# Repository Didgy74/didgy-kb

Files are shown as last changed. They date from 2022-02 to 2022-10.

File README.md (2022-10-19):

# didgy-kb
A catch-all repo for any keyboards I design.

These designs are all designed with [Ergogen](https://github.com/ergogen/ergogen).

# Mitten

This design has the following properties:
 - 30 keys
 - Split
 - Columnar stagger
 - Column splay on the outer columns
 - Wireless
 - Reversible PCB
 - (Very) Low profile (Choc Mini)
 - Choc spacing in Y direction
 - MX spacing in X direction
 - 1u keys for fingers
 - 1.5u keys for thumbs
 - Includes mountplate
 - Standard ProMicro support (Note that it's wireless only, so use a compatible MCU with Bluetooth connectivity)

In short, this design is heavily inspired by the [Ferris](https://github.com/pierrechevalier83/ferris) (or more specifically, the [Sweep](https://github.com/davidphilipbarr/Sweep)). This keyboard is very similar with a few key design differences:
 - Stagger adjusted for hands that have a short index finger
 - Outer columns are splayed
 - Removed one key from innermost column and outermost column.
 - Choc Mini support
 - Larger thumbkeys (1.5u)
 - Designed for wireless operation **only**
 - Includes mountplate

### Information

**Main PCB thickness:** 1.6mm

**Mount plate thickness:** 1.6mm

Mount plate is mostly for making the design sturdier and holding keys in place a bit better.

**Connector:** Molex PicoBlade 2-pin horizontal (Often mislabeled as Micro JST in stores)

**Key switches:** Kailh Choc Mini PG1232 (https://www.aliexpress.com/item/4000277394324.html)

Personal note: Try using 35g springs with linear (black) motion.

**MCU sockets:** Mill-Max Interconnect Machined Pin Socket. Pitch 2.54mm. Height above PCB: 7mm.
Part no. 801-XX-XXX-10-001000. You need at least 12 pins wide, any more can be broken off.

**Underside material:** Neoprene (need actual testing still)

**Keycaps:** MBK profile Choc (https://splitkb.com/collections/switches-and-keycaps/products/blank-mbk-choc-low-profile-keycaps)

**Power switch:** 7-pin micro SPDT

**MCU:** nice!nano

Xiao Seeed was considered for its smaller size, but since battery is mounted under the MCU, the battery would have to become too small anyways.

**MCU socket pins:** Mill-Max gold pins. Part no. 3320-0-00-15-00-00-03-0. (https://splitkb.com/collections/keyboard-parts/products/mill-max-low-profile-sockets?variant=32170972020813)

These could be thicker / longer, fit is not very good.

### Instructions

The MCU has to be mounted **face down** by default.

By default, all jumpers need to be shorted on the **opposite side** of where components are mounted.

### Future design work
I intend to keep iterating on this design over time, here are a few ideas I would like to eventually realize:
 - Add wired connectivity (but only if I, or a number of users request it)
 - Remove a key from the pinky column
 - **Possiby** try out a very low profile rotary encoder
 - Tighter vertical keyspacing (would require custom keycap work)
 - Choc Mini support
 - Add instructions for automatically routing the PCB

Other than that, I'll probably make adjustments to the stagger and key placement over time.

### Configuration 

While this is currently configured to fit my hands specifically, I am very much interested in creating a very parametric design. I try to keep the .yaml file commented enough to easily understand how to modify it. For instance, you could easily switch to using MX spacing by modifying the lines
```yaml
  keyspacingx: cx
  keyspacingy: cy
```
to
```yaml
  keyspacingx: u
  keyspacingy: u
```
and even switch to MX switch footprints by finding the YAML variable named `key_footprints`. Other configurable values currently include margin around key switches, rotation of the home thumbkey. I plan to add more of configuration in the future.

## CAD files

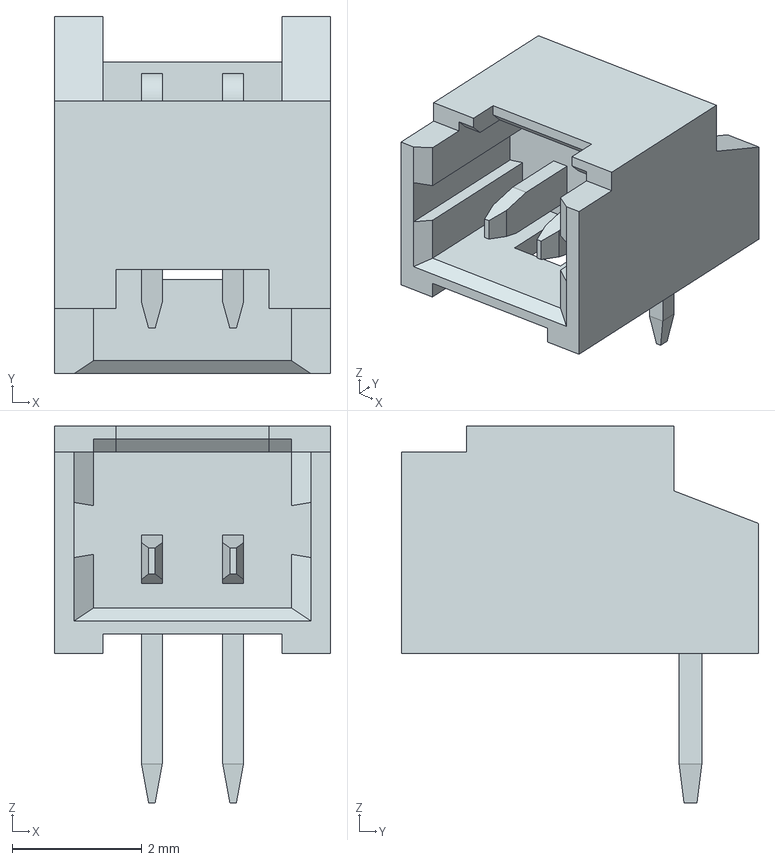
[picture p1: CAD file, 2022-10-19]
530480260.stp
4.25 x 5.50 x 5.80 mm

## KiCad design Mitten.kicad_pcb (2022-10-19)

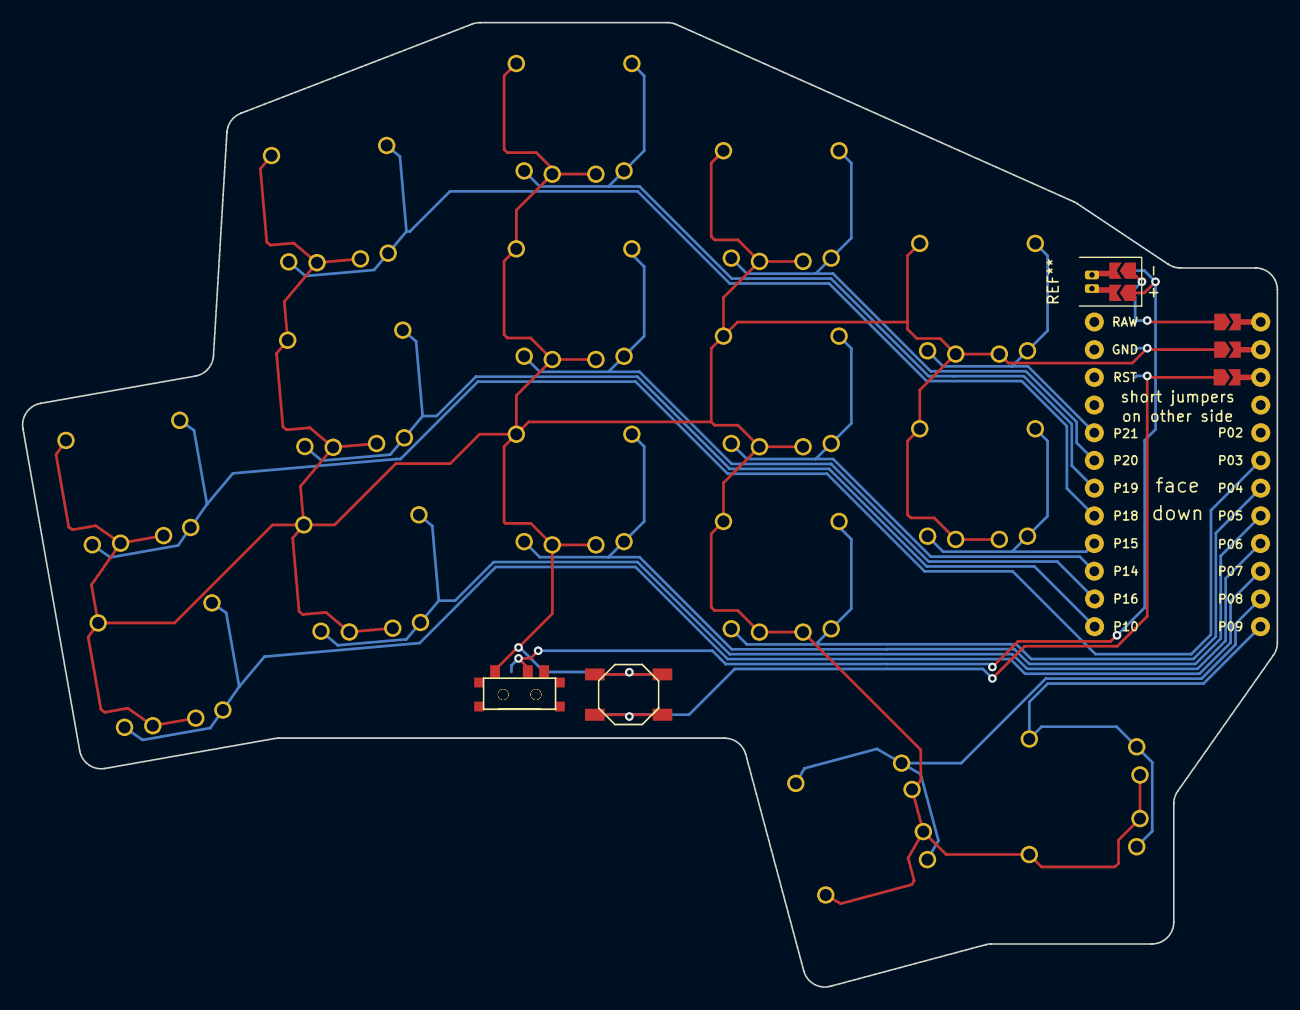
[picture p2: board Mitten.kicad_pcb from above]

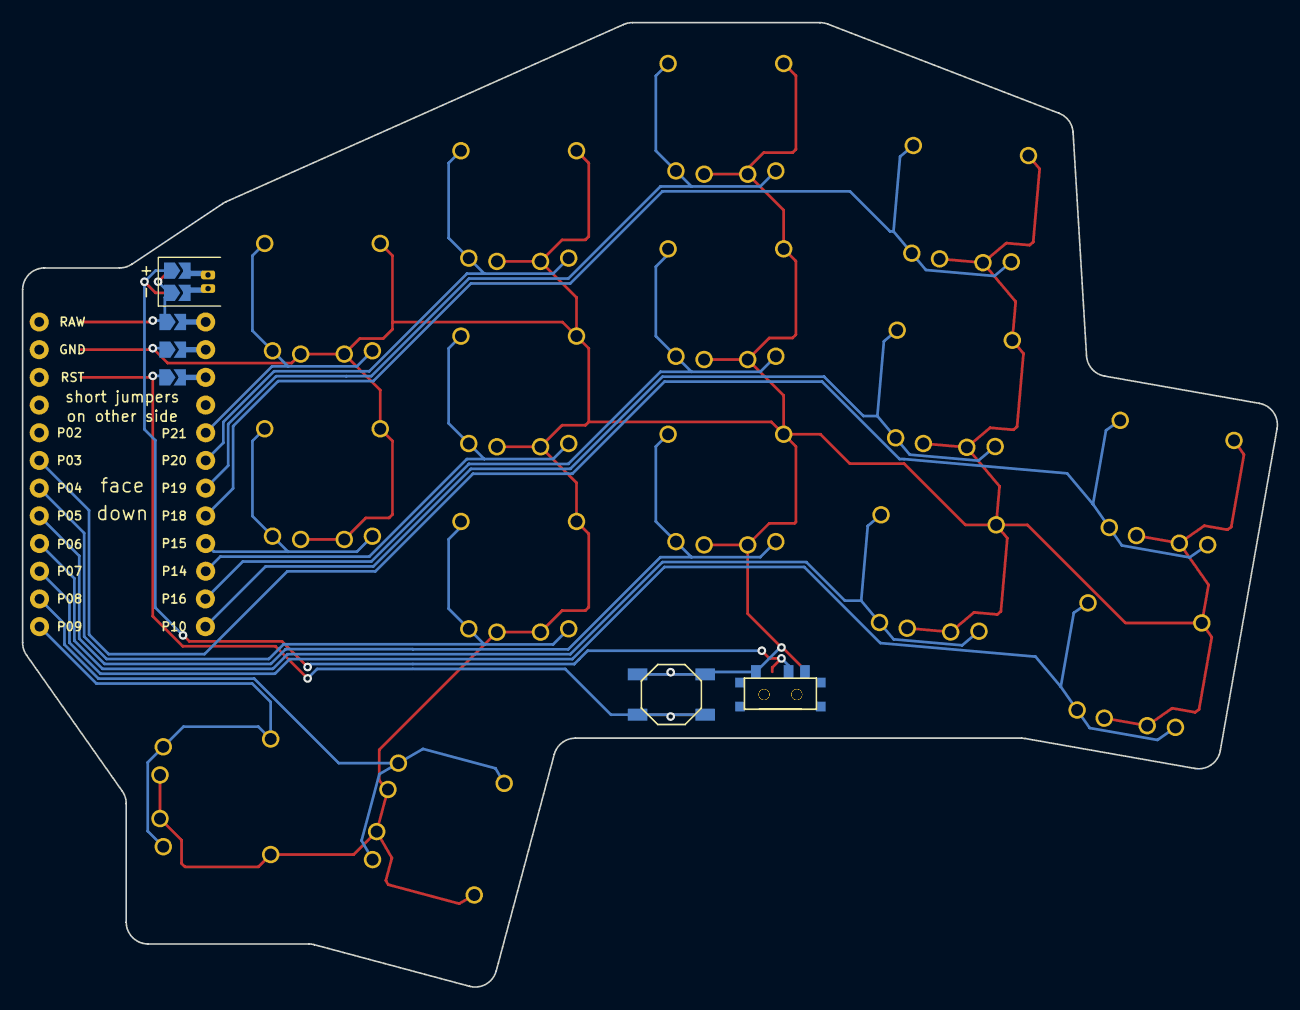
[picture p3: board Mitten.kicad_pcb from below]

Board: 2 copper layers, 115.1 x 88.5 mm, 20 parts (2 on the bottom side), 18 nets.

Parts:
B1, B1#2: SW_TACT_ALPS_SKQGABE010
MCU1: ProMicroReversible
S1, S2, S3, S4, S5, S6, S7, S8, S9, S10, S11, S12, S13, S14, S15: Choc Mini
T1, T1#2: SPDT_C128955

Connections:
Bminus: T1.2, T1#2.2
GND: B1.2, B1#2.2, MCU1.2, S1.2, S2.2, S3.2, S4.2, S5.2, S6.2, S7.2, S8.2, S9.2, S10.2, S11.2, S12.2, S13.2, S14.2, S15.2, T1.1, T1#2.1
RST: B1.1, B1#2.1, MCU1.3
home_default: MCU1.24, S14.1
index_bottom: MCU1.19, S9.1
index_home: MCU1.10, S10.1
index_topmost: MCU1.6, S11.1
innermost_bottom: MCU1.9, S12.1
innermost_topmost: MCU1.5, S13.1
middle_bottom: MCU1.20, S6.1
middle_home: MCU1.11, S7.1
middle_topmost: MCU1.7, S8.1
near_default: MCU1.23, S15.1
pinky_bottom: MCU1.22, S1.1
pinky_home: MCU1.18, S2.1
ring_bottom: MCU1.21, S3.1
ring_home: MCU1.12, S4.1
ring_topmost: MCU1.8, S5.1

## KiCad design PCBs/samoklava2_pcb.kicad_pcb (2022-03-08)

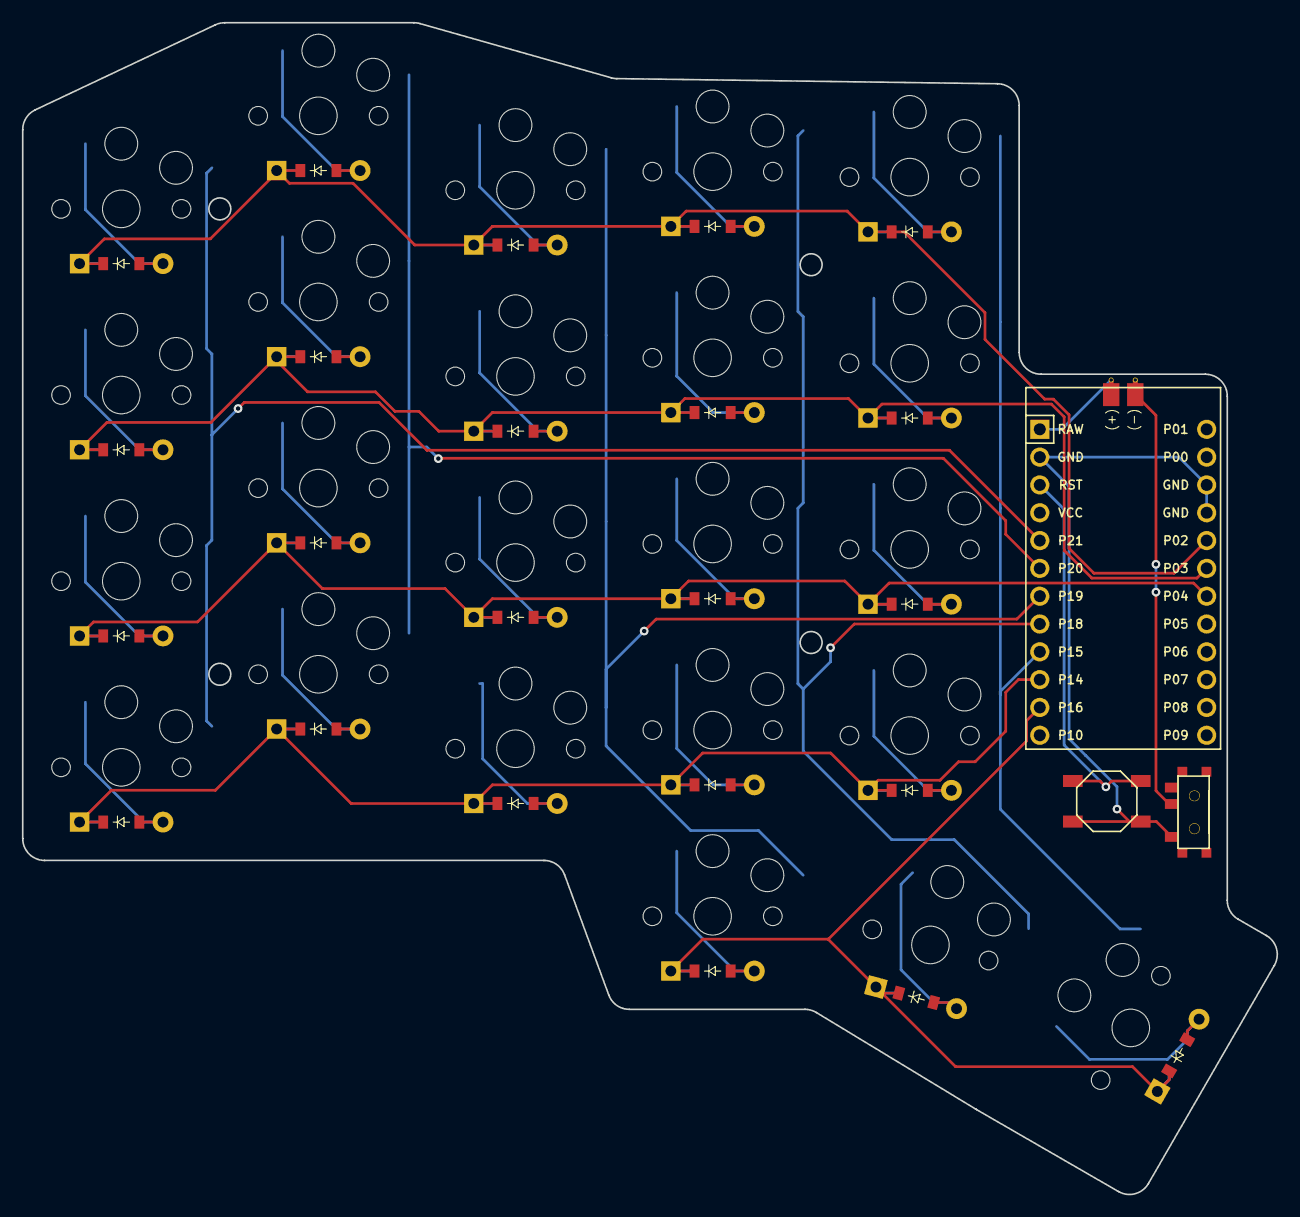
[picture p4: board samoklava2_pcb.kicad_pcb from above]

Board: 2 copper layers, 114.6 x 107.0 mm, 50 parts (0 on the bottom side), 37 nets.

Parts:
B1: SW_TACT_ALPS_SKQGABE010
BT1: Battery_Cell; Battery_pads_reversible
D1, D2, D3, D4, D5, D6, D7, D8, D9, D10, D11, D12, D13, D14, D15, D16, D17, D18, D19, D20, D21, D22, D23: ComboDiode
MCU1: ProMicro
S1, S2, S3, S4, S5, S6, S7, S8, S9, S10, S11, S12, S13, S14, S15, S16, S17, S18, S19, S20, S21, S22, S23: PG1350
T1: SPDT_C128955

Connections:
Bminus: BT1.2, T1.2
GND: B1.2, MCU1.2, MCU1.15, MCU1.16, T1.1
P2: D4.1, D4.2, D8.1, D8.2, D12.1, D12.2, D16.1, D16.2, D20.1, D20.2, MCU1.17
P3: D3.1, D3.2, D7.1, D7.2, D11.1, D11.2, D15.1, D15.2, D19.1, D19.2, MCU1.18
P4: D2.1, D2.2, D6.1, D6.2, D10.1, D10.2, D14.1, D14.2, D18.1, D18.2, MCU1.19
P14: D1.1, D1.2, D5.1, D5.2, D9.1, D9.2, D13.1, D13.2, D17.1, D17.2, MCU1.10
P15: MCU1.9, S17.2, S18.2, S19.2, S20.2, S23.2
P16: D21.1, D21.2, D22.1, D22.2, D23.1, D23.2, MCU1.11
P18: MCU1.8, S13.2, S14.2, S15.2, S16.2, S22.2
P19: MCU1.7, S9.2, S10.2, S11.2, S12.2, S21.2
P20: MCU1.6, S5.2, S6.2, S7.2, S8.2
P21: MCU1.5, S1.2, S2.2, S3.2, S4.2
RAW: BT1.1, MCU1.1
RST: B1.1, MCU1.3
far_default: D23.1, D23.2, S23.1
home_default: D22.1, D22.2, S22.1
index_bottom: D13.1, D13.2, S13.1
index_home: D14.1, D14.2, S14.1
index_top: D15.1, D15.2, S15.1
index_topmost: D16.1, D16.2, S16.1
innermost_bottom: D17.1, D17.2, S17.1
innermost_home: D18.1, D18.2, S18.1
innermost_top: D19.1, D19.2, S19.1
innermost_topmost: D20.1, D20.2, S20.1
middle_bottom: D9.1, D9.2, S9.1
middle_home: D10.1, D10.2, S10.1
middle_top: D11.1, D11.2, S11.1
middle_topmost: D12.1, D12.2, S12.1
near_default: D21.1, D21.2, S21.1
pinky_bottom: D1.1, D1.2, S1.1
pinky_home: D2.1, D2.2, S2.1
pinky_top: D3.1, D3.2, S3.1
pinky_topmost: D4.1, D4.2, S4.1
ring_bottom: D5.1, D5.2, S5.1
ring_home: D6.1, D6.2, S6.1
ring_top: D7.1, D7.2, S7.1
ring_topmost: D8.1, D8.2, S8.1

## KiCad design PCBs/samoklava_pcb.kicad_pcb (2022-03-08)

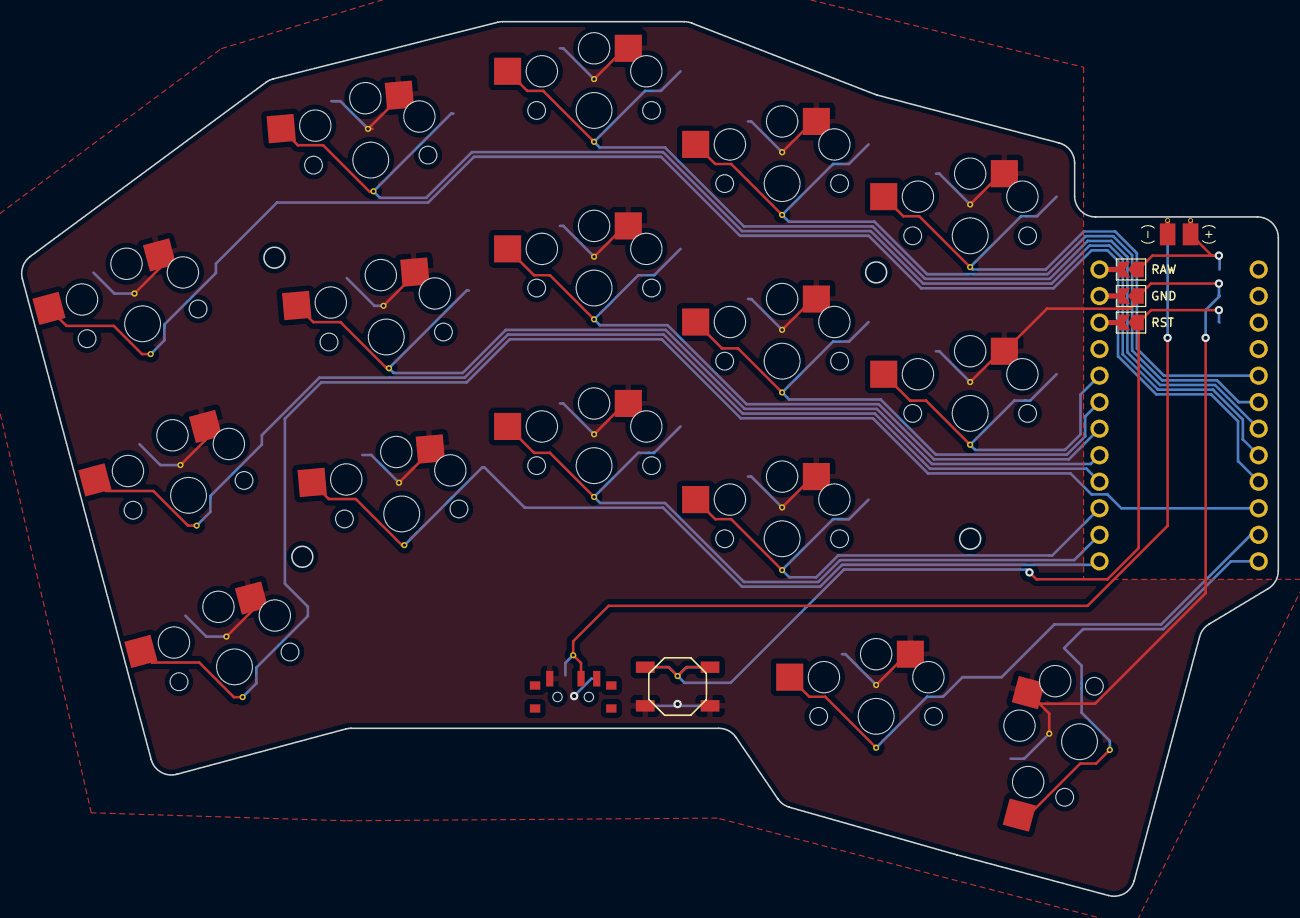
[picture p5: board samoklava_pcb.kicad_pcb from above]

Board: 2 copper layers, 120.3 x 83.7 mm, 21 parts (1 on the bottom side), 20 nets.

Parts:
B1, B2: SW_TACT_ALPS_SKQGABE010
BT1: Battery_Cell; Battery_pads_reversible
MCU1: Val**; ProMicroSimpleJumper
S1, S2, S3, S4, S5, S6, S7, S8, S9, S10, S11, S12, S13, S14, S15, S16: PG1350
T1: Power_reversible

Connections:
Bminus: BT1.2, T1.2
GND: B1.2, B2.2, MCU1.2, S1.1, S2.1, S3.1, S4.1, S5.1, S6.1, S7.1, S8.1, S9.1, S10.1, S11.1, S12.1, S13.1, S14.1, S15.1, S16.1, T1.1
P2: MCU1.17, S14.2
P3: MCU1.18, S12.2
P4: MCU1.19, S9.2
P5: MCU1.20, S6.2
P6: MCU1.21, S3.2
P7: MCU1.22, S1.2
P8: MCU1.23, S15.2
P9: MCU1.24, S16.2
P10: MCU1.12, S4.2
P14: MCU1.10, S10.2
P15: MCU1.9, S2.2
P16: MCU1.11, S7.2
P18: MCU1.8, S5.2
P19: MCU1.7, S8.2
P20: MCU1.6, S11.2
P21: MCU1.5, S13.2
RAW: BT1.1, MCU1.1
RST: B1.1, B2.1, MCU1.3

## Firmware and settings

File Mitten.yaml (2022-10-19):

units:
  choc_cutout_width: 13.50
  choc_cutout_height: 12.50
  
  promicro_width: 18
  promicro_height: 35
  mcuarea_width: promicro_width
  mcuarea_height: promicro_height
  mcuarea_bottom_offset_height: 1.5
  mcuarea_outermargin: 0.25
  componentarea_width: mcuarea_width + 2 mcuarea_outermargin
  componentarea_height: mcuarea_height
  

  
  # Configurable values
  key_fooprint_width: cx
  key_fooprint_height: cy
  keyspacingx: u
  keyspacingy: cy
  keyspacingx_innermost: cx
  key_outermargin: 0
  keycap_1u_width: cx - 0.5
  keycap_1u_height: cy - 0.5
  keycap_15u_width: 1.5 cx - 0.5
  choc_keycap_cornerradius: 1
  outline_corner_radius: 2
  thumbfan_outer_rotate: -0
  thumbfan_offsety: -2.5
  key_plate_cutout_width: choc_cutout_width
  key_plate_cutout_height: choc_cutout_height
  powerswitch_width: 8
  powerswitch_height: 4
  powerswitch_plate_margin: 1
  button_width: 8
  button_height: 6
  powerswitch_button_spacing: 2
  
  pinky_splay: 5
  ring_splay: 5
  
  ring_stagger: 6
  middle_stagger: 7
  index_stagger: 8
  innermost_stagger: 0.5 keyspacingy
  
  
  
  # Not configurable
 
  sum_splay: pinky_splay + ring_splay 
  buttonarea_width: powerswitch_width + button_width + powerswitch_button_spacing
  buttonarea_height: 6
  
  
  visual_x: 1
  visual_y: 1
  
points:

  zones:
    matrix:
      key:
        width: key_fooprint_width
        height: key_fooprint_height
        padding: keyspacingy
        tags:
          switch_cutout: true
          key_1u: true
          
        # Footprints for key-switches.  
        footprints: &key_footprints
          choc_hotswap:
            type: choc
            params:
              keycaps: true
            nets:
              from: =colrow
              to: GND
            anchor:
              rotate: 0
      columns:
        pinky:
          rotate: sum_splay
          key.column_net: col0_pinky
          rows:
            bottom:
              row_net: row2_bottom
            home:
              row_net: row1_home
        ring:
          origin: [ -0.5 keyspacingx, -0.5 keyspacingy ]
          rotate: -pinky_splay
          stagger: ring_stagger
          spread: keyspacingx
          key.column_net: col1_ring
          rows:
            bottom:
              row_net: row2_bottom
            home:
              row_net: row1_home
            topmost:
              row_net: row0_top
        middle:
          origin: [ -0.5 keyspacingx, -0.5 keyspacingy ]
          rotate: -ring_splay
          stagger: middle_stagger
          spread: keyspacingx
          key.column_net: col2_middle
          rows:
            bottom:
              row_net: row2_bottom
            home:
              row_net: row1_home
            topmost:
              row_net: row0_top
        index:
          stagger: -index_stagger
          spread: keyspacingx
          key.column_net: col3_index
          rows:
            bottom:
              row_net: row2_bottom
            home:
              row_net: row1_home
            topmost:
              row_net: row0_top
        innermost:
          stagger: keyspacingy - innermost_stagger
          spread: keyspacingx_innermost
          key.column_net: col4_innermost
          rows:
            bottom:
              row_net: row2_bottom
            topmost:
              row_net: row0_top
    thumbfan:
      anchor:
        - ref: matrix_index_bottom
          shift: [0, -(0.5 keyspacingx + 0.5 keyspacingy)]
          affect: y
        - ref: matrix_innermost_bottom
          shift: [0.5 keyspacingx, 0]
          affect: x
        - shift: [0, thumbfan_offsety]
      key:
        width: 1.5 key_fooprint_width
        height: key_fooprint_height
        tags.switch_cutout: true
        rotate: 90
        footprints: *key_footprints
      columns:
        home:
          rows:
            default:
              tags.key_15u: true
              column_net: col4_innermost
              row_net: P5
        near:
          rotate: 15
          origin: [ 0.5 keyspacingy, -0.75 key_fooprint_width ]
          spread: -keyspacingy
          rows:
            default:
              tags.key_15u: true
              column_net: col3_index
              row_net: P5
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

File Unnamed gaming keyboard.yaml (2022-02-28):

units:
  choc_cutout_width: 14
  choc_cutout_height: choc_cutout_width
  choc_keycap_cornerradius: 2
  promicro_width: 18
  promicro_height: 38
  promicro_bottom_offset: 3
  # Offset from top-right / top-left of the MCU
  batterypin_offsetx: -5
  batterypin_offsety: -2
  mcuarea_width: promicro_width
  mcuarea_height: promicro_height
  componentarea_width: mcuarea_width + 1
  componentarea_height: mcuarea_height
  promicro_outermargin: 0.5
  
  # Configurable values
  keyspacingx: cx
  keyspacingy: cy
  keycap_width: keyspacingx - 0.5
  keycap_height: keyspacingy - 0.5
  key_outermargin: 1
  key_chocsocket_margin: 1
  outline_corner_radius: 2
  screwhole_radius: 1
  resetswitch_margin: 10
  reset_power_spacing: 10
  componentarea_offsety: 3
  
  
  
  
points:

  zones:
  
    # The main finger keys.
    matrix:
      key:
        padding: keyspacingy
        tags:
          is_key: true
          key_1u: true
          key_15u: false
        footprints: &key_footprints
          choc_hotswap:
            type: choc
            params:
              hotswap: true
              reverse: false
              keycaps: true
            nets:
              from: =colrow
              to: =column_net
          diode:
            type: diode
            nets:
              from: =colrow
              to: =row_net
            anchor:
              shift: [ 0, -5 ]
        
      columns:
        pinky:
          key:
            column_net: P21
        ring:
          stagger: 0.5 keyspacingy
          spread: keyspacingx
          key:
            column_net: P20
        middle:
          stagger: -0.4 keyspacingy
          spread: keyspacingx
          key:
            column_net: P19
        index:
          stagger: 0.1 keyspacingy
          spread: keyspacingx
          key:
            column_net: P18
        innermost:
          stagger: -0.5
          spread: keyspacingx
          key:
            column_net: P15
      rows:
        bottom:
          row_net: P14
        home:
          row_net: P4
        top:
          row_net: P3
        topmost:
          row_net: P2

    thumbfan:
      key:
        tags.is_key: true
        tags.key_1u: true
        tags.key_15u: false
        footprints: *key_footprints
      anchor:
        ref: matrix_index_bottom
        shift: [0 keyspacingx, -1 keyspacingy]
      columns:
        near:
          rotate: 0
          origin: [-0.5 keyspacingx, -0.5 keyspacingy]
          key:
            column_net: P19
        home:
          spread: keyspacingx
          rotate: -15
          origin: [-0.5 keyspacingx, -0.5 keyspacingy]
          key:
            column_net: P18
        far:
          spread: keyspacingx
          rotate: -15
          origin: [-0.5 keyspacingx, -0.5 keyspacingy + 1 ]
          key:
            rotate: 90
            tags.key_1u: false
            tags.key_15u: true
            column_net: P15
      rows:
        default:
          row_net: P16
        
        
    componentarea:
      anchor:
        - ref: matrix_innermost_bottom
          affect: x
          shift: [ 0.5 keyspacingx + key_chocsocket_margin + 0.5 componentarea_width, 0 ]
        - ref: matrix_index_bottom
          affect: y
          shift: [ 0, -0.5 keyspacingy + 0.5 componentarea_height + componentarea_offsety ]
    
    mcu:
      anchor:
        ref: componentarea_default_default
        shift:
          - 0.5 componentarea_width - 0.5 promicro_width - promicro_outermargin
          - 0.5 componentarea_height - 0.5 promicro_height
        
    powerswitch:
      key:
        tags.is_key: false
      anchor:
        - ref: componentarea_default_default
          affect: x
          shift: [ 0.5 componentarea_width, 0.5 componentarea_height ]
        - ref: mcu_default_default
          affect: y
          shift: [ 0.5 promicro_width, -0.5 promicro_height + promicro_bottom_offset ]
        - shift: [ -3, -5 ]
          
    resetswitch:
      anchor:
        ref: powerswitch_default_default
        shift: [-8, 1]
      key:
        tags.is_key: false
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

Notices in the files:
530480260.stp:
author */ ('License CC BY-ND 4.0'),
